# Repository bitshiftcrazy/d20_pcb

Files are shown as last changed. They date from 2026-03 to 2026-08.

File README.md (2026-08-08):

# d20 PCB

A handheld electronic D20 built as a DnD-themed PCB project.

The board uses an ATtiny84, charlieplexed LEDs, capacitive touch input,
custom animations, EEPROM-backed "attunement", and hidden easter eggs to
turn a PCB into a slightly magical-feeling tabletop artifact. For dice
rolls, dramatic failures, heroic last minutes, and other shenanigans ;)

<p align="center">
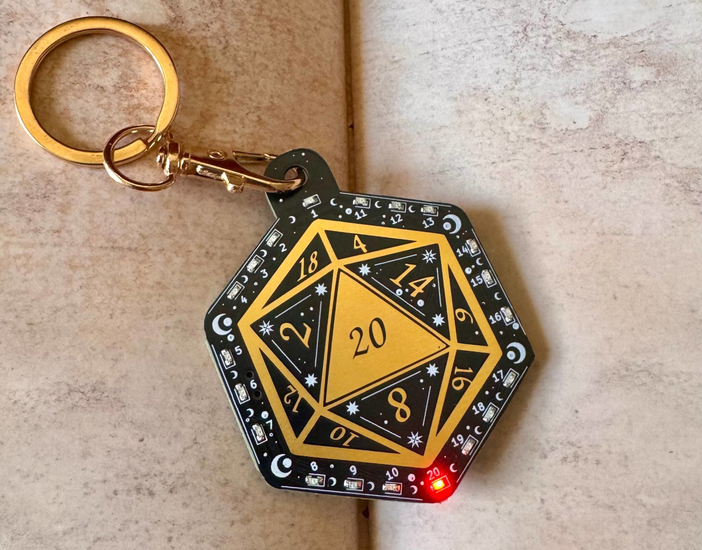
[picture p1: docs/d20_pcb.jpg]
  
</p>

## Features

- Electronic D20 with animated rolls
- Capacitive touch dice rolling
- Character-specific animation variants
- EEPROM-backed attunement system
- Hidden easter eggs and secret modes
- Fully open hardware and open source firmware
- Mildly questionable choices and amounts of whimsy

## Usage

### Power On

Turn on the board using the slide switch on the right side.

The board spends most of its existence asleep, patiently waiting for
an adventurer to wake it.

### Wake Up

Press the push button on the back once to wake the board.

The LEDs should come to life shortly afterwards.

### Rolling

Rolls can be triggered either by:

- pressing the push button
- briefly touching and releasing the `20` touch pad

The pushbutton has the power to interrupt rolls, should fate require it.

The touch sensor is intentionally configured conservatively to avoid
accidental triggers and random table wizardry (everyone who's seen an actual Pen and Paper table will know why).

Touch works best while holding the board in your hand and touching the
pad between thumb and index finger (there has been some discussion about
this...).

Touch sensitivity can be adjusted in `firmware/src/touch.c`.

See the firmware README for more information.

## Attunement

The board features a small "attunement" system inspired by magical items
in tabletop RPGs.

On first activation, the firmware stores a tiny hardware-specific value in
EEPROM based on touch pad readings. This subtly affects animation timing
and behavior, making each board feel ever so slightly different.

## Repository Structure

```text
hardware/   KiCad PCB design, manufacturing files and artwork
firmware/   ATtiny84 firmware and test infrastructure
docs/       Images and documentation assets
```

Detailed instructions are available in:

- [hardware/README.md](hardware/README.md)
- [firmware/README.md](firmware/README.md)

## Easter Eggs

The firmware contains several hidden interactions and modes and, yeah, an attitude.

Some are obvious.
Some are less obvious.

Some still haven't been found yet.

<p align="center">
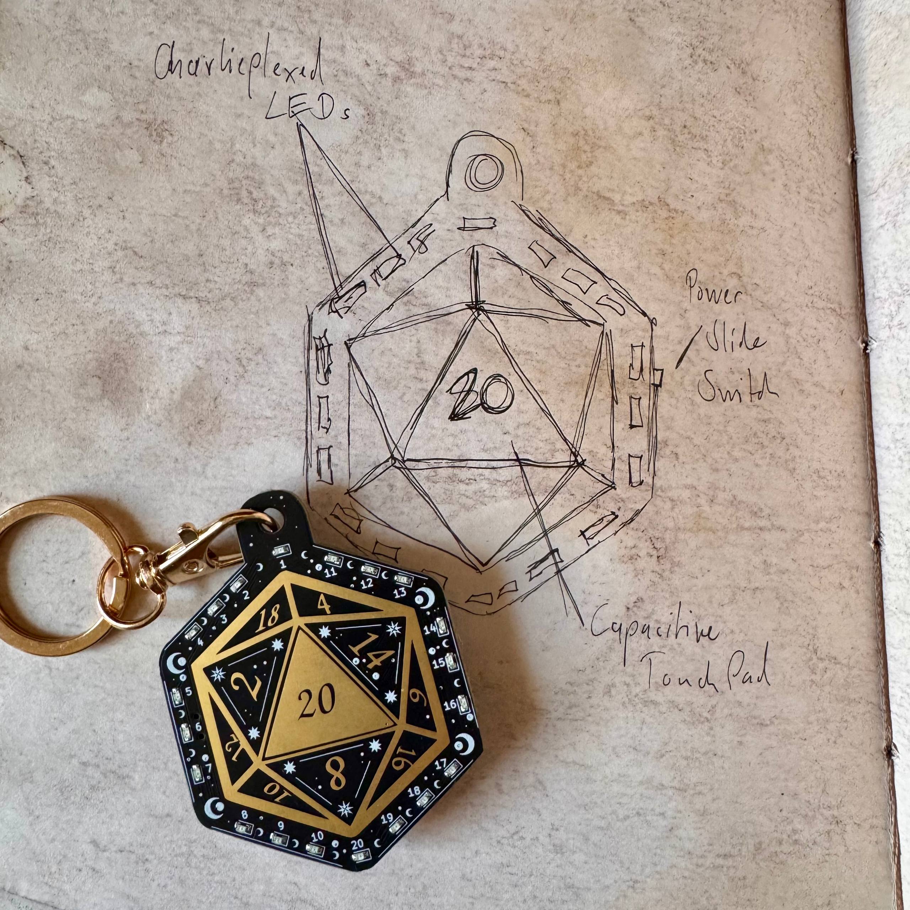
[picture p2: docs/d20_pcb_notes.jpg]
  
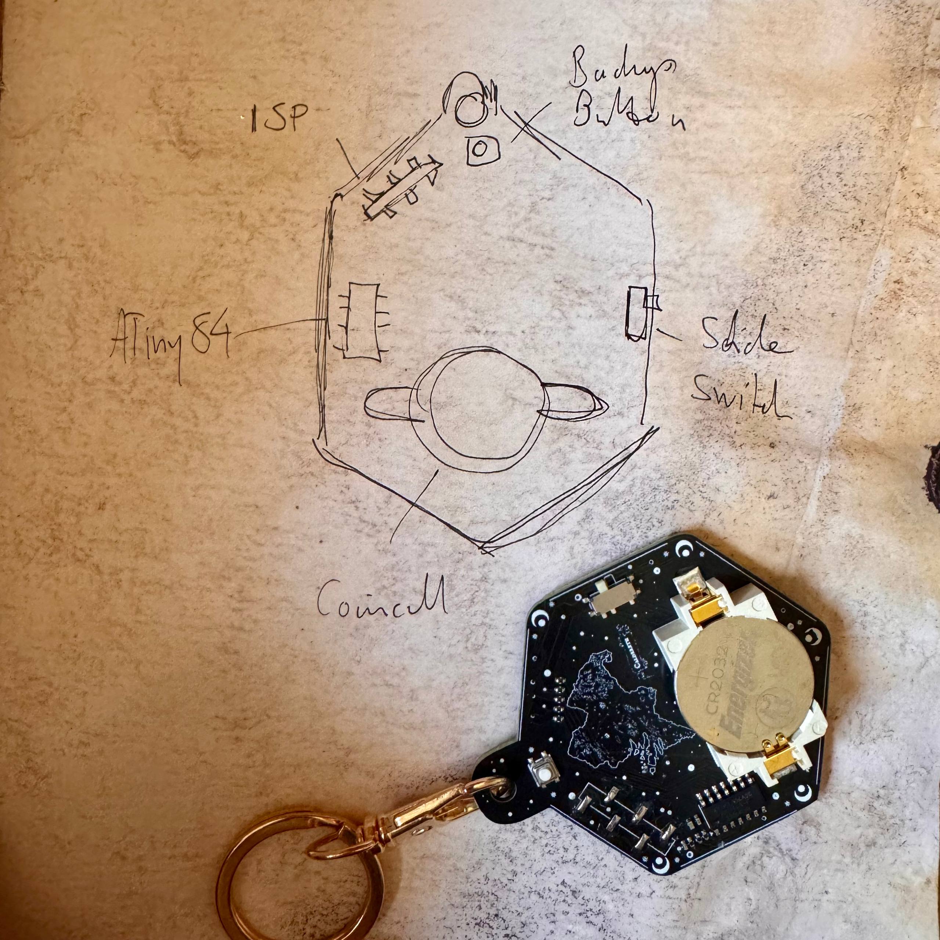
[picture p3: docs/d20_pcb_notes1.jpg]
  
</p>

## Project Background

This project originally started as a handmade DnD-themed gift for my
players, with far more LEDs, firmware, and suspicious EEPROM usage than originally planned.
And now it's an open hardware project.

There's customisation for both the players and the campaign hidden
throughout the project because of how it came to be.
The different character's animation can be interpreted as flavour and compiled in to your liking.

## Further Reading

- Project blog post: https://missmolerat.com/posts/d20_pcb/
- Hackaday: https://hackaday.com/2026/05/25/slightly-sentient-d20-might-subtly-shift-your-rolls/

## Licenses

- Hardware: CERN Open Hardware License
- Firmware: GPL-3.0-only

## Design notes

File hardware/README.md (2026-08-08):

# d20 PCB – Hardware

<p align="center">
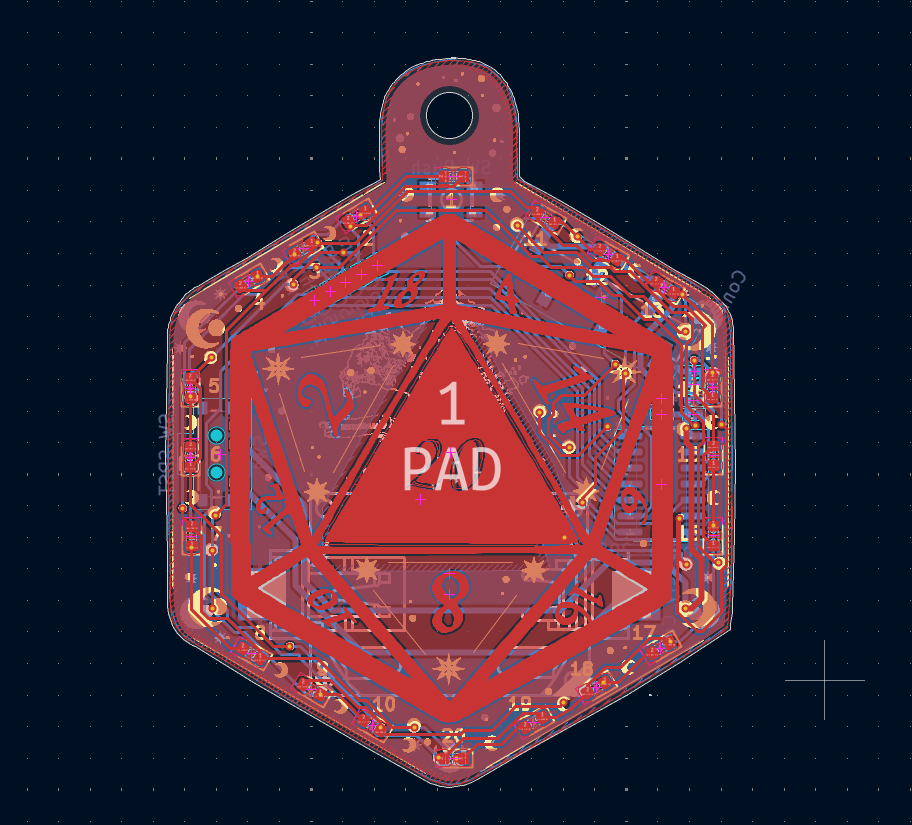
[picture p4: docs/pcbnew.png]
  
</p>

This directory contains the KiCad design files, artwork, and
manufacturing outputs for the d20 PCB.

The board is a small ATtiny-based electronic die with 20 LEDs arranged
around the edge of a d20-shaped PCB. A capacitive touch pad triggers a
roll animation and displays a random result.

## Hardware Overview

Main components:

- ATtiny84 microcontroller
- 20 LEDs arranged in a ring (charlieplexed)
- Capacitive touch pad for input
- Coin cell battery holder
- Push button (optional backup input)

## Directory Structure

```text
d20_pcb.kicad_pro
d20_pcb.kicad_sch
d20_pcb.kicad_pcb
```

KiCad project files.

```text
artwork/
```

SVG artwork used for silkscreen and copper layers.

```text
libraries/
```

Project-local KiCad symbol and footprint libraries.

```text
fabrication/
```

Generated manufacturing files:

- `gerbers/`
- `drill/`
- `bom/`
- `pickplace/`

```text
fabrication/jlcpcb/
```

Vendor-specific BOM and placement files for JLCPCB assembly.

### JLCPCB Component Substitutions

Component availability at JLCPCB/LCSC changes over time. During a 2026
JLCPCB assembly order, the following substitutions were proposed for the
v3 BOM:

| Designator | Original value / function | Substitute | Notes |
| --- | --- | --- | --- |
| C2 | 10 µF | C7472949 — HGC0402R5106M100NTEJ | 10 µF, 10 V, 0402 MLCC. Original C6119763 was out of stock. |
| R1–R5 | 150 Ω | C2909321 — FRC0402F1500TS | 150 Ω, 1%, 0402 |
| R7–R8 | 10 kΩ | C723366 — RT0402FRE0710KL | 10 kΩ, 1%, 0402 thin-film resistor, YAGEO |
| J1 | ISP header | C48641755 — HX PM2.54-1x6P | SMD female 1×6 header with staggered pins. The original BOM entry had no LCSC part number. |
| J2 and G* | — | DNP | No physical components fitted. |

The suggested C2 replacement is a ceramic MLCC rather than the capacitor
specified in the original BOM. Component substitutions should always be
reviewed before ordering, since stock and JLCPCB/LCSC part assignments
can change.

Thanks to [@dmaglio](https://github.com/dmaglio) for reporting these
substitutions in [issue #1](https://github.com/bitshiftcrazy/d20_pcb/issues/1).

## KiCad Project

The board is designed using KiCad.

Main files:

- `d20_pcb.kicad_pro` – project file
- `d20_pcb.kicad_sch` – schematic
- `d20_pcb.kicad_pcb` – PCB layout

The project uses local libraries located in:

```text
libraries/
```

## Artwork

Silkscreen and copper artwork is stored as SVG files in:

```text
artwork/
```

These files were used to create decorative PCB elements such as:

- board outline
- line art
- map on the back
- decorative stars and moons

## Manufacturing

<p align="center">
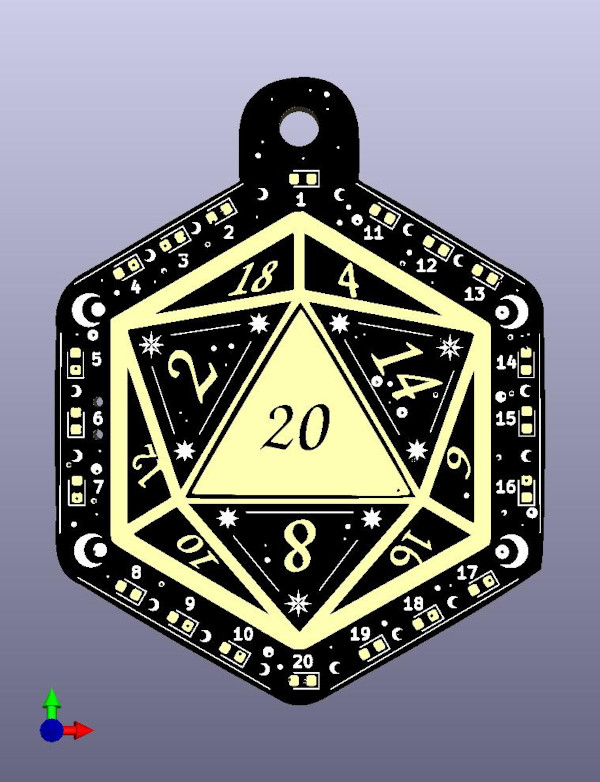
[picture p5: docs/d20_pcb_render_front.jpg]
  
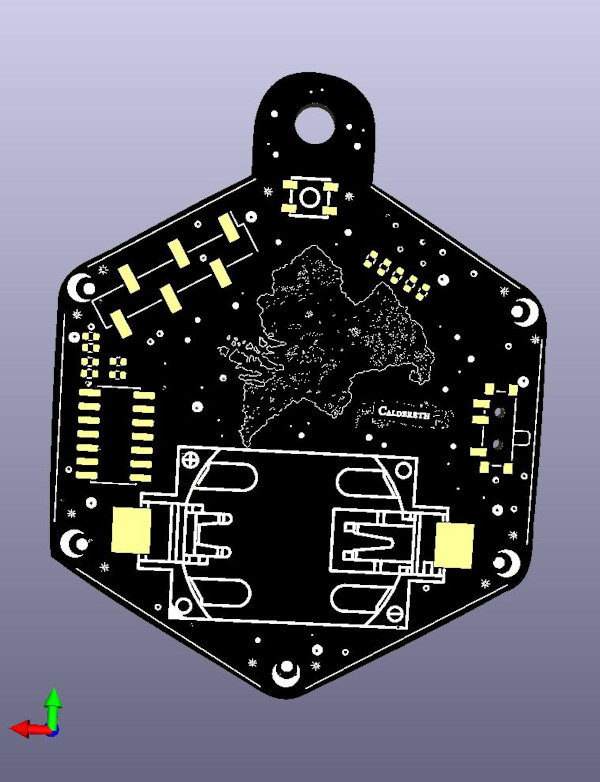
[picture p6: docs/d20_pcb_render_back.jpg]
  
</p>

All required manufacturing outputs are located in:

```text
fabrication/
```

To manufacture the board:

1. Upload files from `fabrication/gerbers/` to a PCB manufacturer.
2. Use files from `fabrication/drill/` for drilling information.
3. Use the BOM and pick-and-place files for assembly.

Note: the more detailed assembly BOM with parts and values is located in:

```text
fabrication/jlcpcb/
```

Alternatively:

The files in `fabrication/releases/` contain the currently tested and
successfully manufactured board revision.

If you modify the KiCad source files, you should regenerate and review
all fabrication outputs (Gerbers, drill files, BOM, and pick-and-place
files) before ordering boards.

Even small PCB edits can invalidate previously generated fabrication
files.

If you are new to PCB manufacturing, it is recommended to use the tested
release files directly instead of generating new Gerbers yourself.

## Regenerating Fabrication Files

Manufacturing files can be regenerated from KiCad:

```text
PCB Editor → Fabrication Outputs
```

## Assembly

### Supplies

* soldering iron (alternatively: heat plate or hot air)
* solder (alternatively: solder paste)
* flux
* fume extractor or a well-ventilated space

### Parts

Many of the parts are influenced by what I had at home at the time.

Quite a few can be swapped for whatever matches the footprint. I found that old TV remotes are wonderful donors for slide switches and push buttons, for example. At least that's where I got these components from.

* 20 x SMD LEDs (0603)
* 1 x 0.1 µF capacitor (0402)
* 1 x 10 µF capacitor (0402)
* 1 x 10 nF capacitor (0402)
* 5 x 150 Ω resistors (0402)
* 2 x 10 kΩ resistors (0402)
* 1 x 1 MΩ resistor (0402)
* 1 x Keystone 1060TR battery holder
* 1 x CR2032 coin cell battery
* 1 x ATtiny84-20P Microchip ATTINY84A-SSF
* 1 x SPDT slide switch (see footprint; many ~8 mm SMD slide switches will fit, AliExpress has quite a few)
* 1 x push button (same here; 3.4 x 3.4 mm SMD push buttons often work)

I'd really love to point towards specific components for the slide switch or push button. But apart from sourcing the part via JLCPCB assembly or scavenging it, I have none.

Really, have faith: as long as you manage to connect the footprint pads with the part pins somehow, a lot of switches will work here (source: trust me bro).

### Soldering

<p align="center">
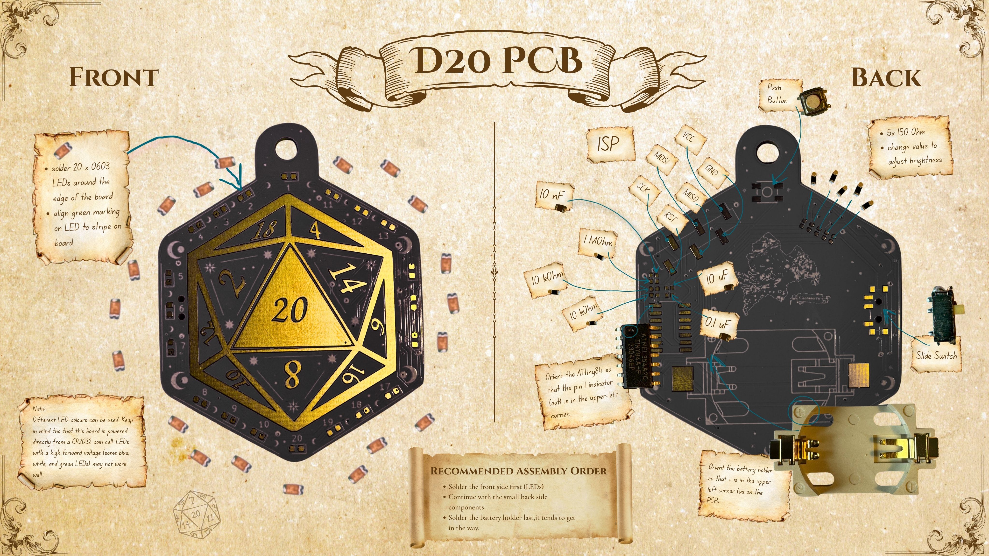
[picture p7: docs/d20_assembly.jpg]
  
</p>

## Colour Suggestions

The board was intentionally designed with colourful solder masks and
ENIG finishes in mind.

~~I'd really love to see a pink board!~~

Mission accomplished :D

<p align="center">
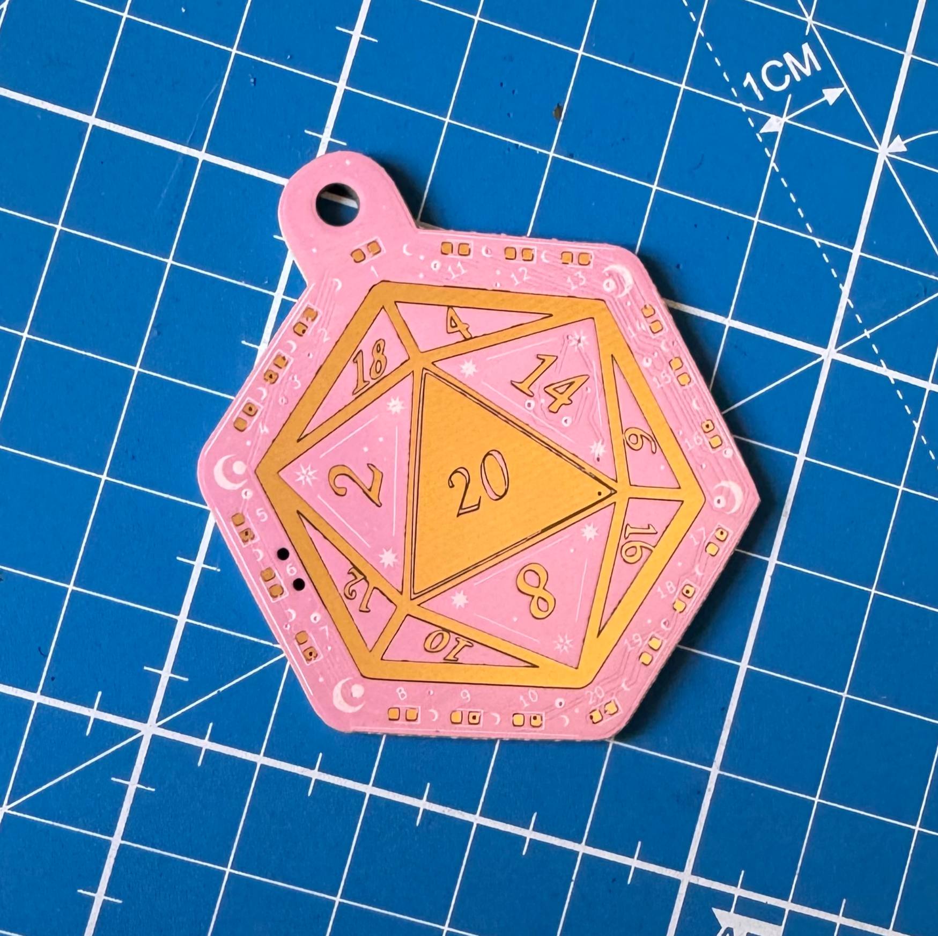
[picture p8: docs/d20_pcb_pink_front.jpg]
  
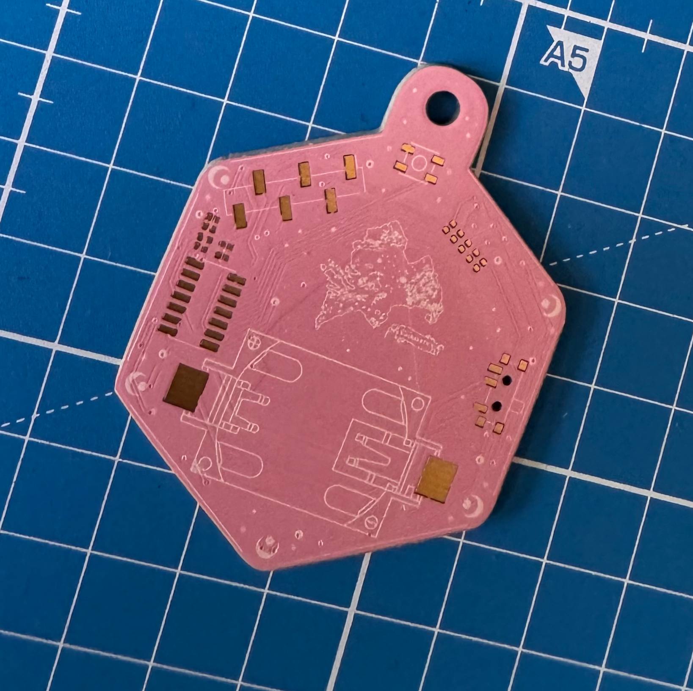
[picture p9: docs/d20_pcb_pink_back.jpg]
  
</p>

<p align="center">
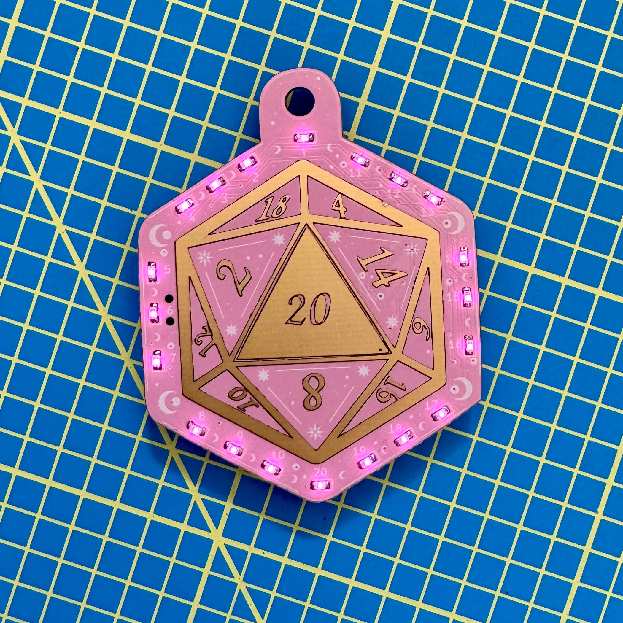
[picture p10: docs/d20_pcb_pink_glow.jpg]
  
</p>

For comparison, here are the original render concepts:

<p align="center">
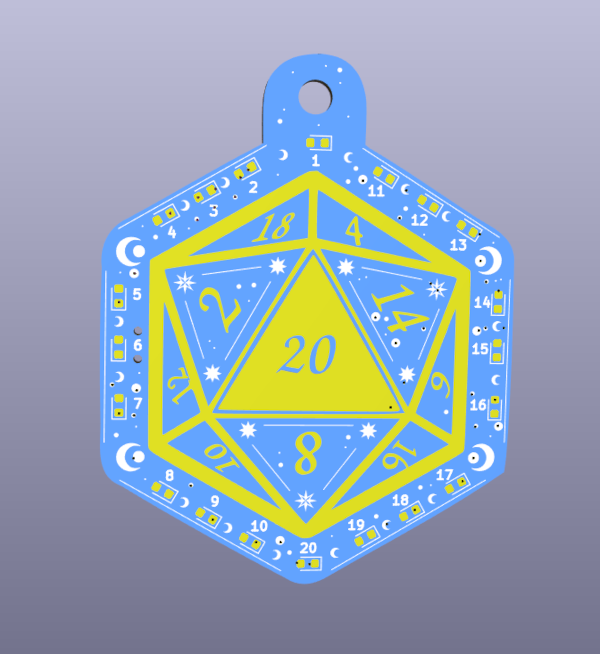
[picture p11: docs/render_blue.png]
  
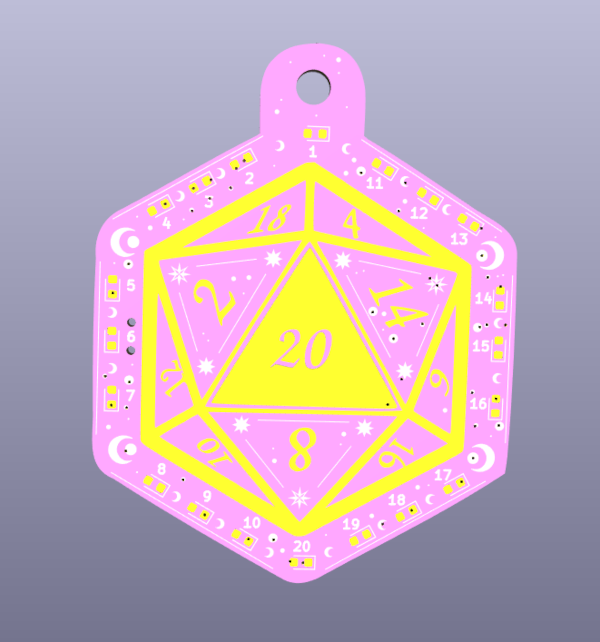
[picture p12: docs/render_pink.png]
  
</p>

## License

This hardware design is licensed under the CERN Open Hardware Licence
Version 2 – Strongly Reciprocal (CERN-OHL-S v2).

You may manufacture, modify and sell products based on this design,
provided that any modifications to the design files are released under
the same license.

The full license text is available in the LICENSE file.

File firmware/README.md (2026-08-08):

# d20 PCB Firmware

Firmware for the d20 PCB project.

This firmware runs on an **ATtiny84** and controls the charlieplexed LEDs,
button input, capacitive touch input, EEPROM-backed attunement state, dice
roll logic, animations, and some easter eggs.

The following instructions assume firmware is built and flashed from Linux.

## Hardware Requirements

To program the board, you need:

- d20 PCB with ATtiny84 (see [hardware/](../hardware))
- ISP programmer, for example USBasp
- ISP connection to the board
- Linux machine with AVR toolchain installed

The Makefile currently assumes a USBasp programmer.

## Software Requirements

Install the AVR toolchain.

### Arch Linux

```sh
sudo pacman -S avr-gcc avr-libc avrdude make
```

### Debian / Ubuntu

```sh
sudo apt install gcc-avr avr-libc avrdude make
```

## Building

From the repository root:

```sh
cd firmware
make
```

This builds the default firmware and prints AVR memory usage.

Build output is written to:

```text
build/
```

The generated firmware image is:

```text
build/d20_firmware_4.hex
```

The default character ID is currently `4`.

## Character Selection

Since the project originates from a gift for my DnD players, the firmware
supports different character-specific builds through `CHARACTER_ID`.

```sh
make CHARACTER_ID=4
```

Known character IDs:

```text
1 = ASHTAN
2 = BARTHOLOMEW
3 = FAWN
4 = SALEM
5 = VII
```

Example:

```sh
make flash CHARACTER_ID=2
```

## Fuse Bits

Before flashing the firmware for the first time, program the ATtiny84 fuse
bits:

```sh
make fuses
```

This configures the microcontroller to use the 8 MHz clock settings expected by the firmware.

Fuse bits only need to be programmed once per microcontroller.

## Flashing

To build and flash the firmware with a USBasp programmer:

```sh
make flash
```

This uses:

```text
avrdude -c usbasp -p t84 -B 10
```

To flash a different character firmware:

```sh
make flash CHARACTER_ID=5
```

## Diagnostic Test Firmware

The firmware includes small functional and diagnostic test builds.

These are not full unit tests. They are intended to flash special test
firmware onto the board to verify individual hardware or firmware features.

Build a test firmware without flashing:

```sh
make test TEST_CASE=attunement
```

Build and flash a selected test firmware:

```sh
make flash-test TEST_CASE=adc_band_finder
```

Available test cases:

```text
led_walk
button_toggle
button_hold
adc_range
touch_detect
touch_long
adc_band_finder
attunement
sequence
```

Shortcut targets are also available:

```sh
make test-led-walk
make test-button-toggle
make test-button-hold
make test-adc-range
make test-touch-detect
make test-touch-long
make test-adc-band-finder
make test-attunement
make test-sequence
```

## EEPROM Helpers

Read the ATtiny84 EEPROM into `build/eeprom.hex`:

```sh
make eeprom-read
```

Read and print EEPROM contents:

```sh
make eeprom-view
```

This is useful for checking attunement state and debugging persistent firmware
state.

## Cleaning

Remove build output:

```sh
make clean
```

## Makefile Overview

Useful targets:

```text
make all          Build firmware hex and show size
make flash        Build and flash normal firmware
make test         Build diagnostic test firmware
make flash-test   Build and flash diagnostic test firmware
make size         Show AVR memory usage
make eeprom-read  Read EEPROM into build/eeprom.hex
make eeprom-view  Read and print EEPROM contents
make clean        Remove build output
make help         Show Makefile help
```

Useful options:

```text
CHARACTER_ID=N    Select character firmware variant
TEST=1            Build test firmware instead of normal firmware
TEST_CASE=name    Select diagnostic test case
```

## Firmware Configuration and Tuning

The main configuration is done in `src/config.h`.

Touch sensing can be adjusted in `src/touch.c`.

You can use the diagnostic test firmware targets:

- `test-adc-range`
- `test-adc-band-finder`

to inspect and tune touch detection thresholds for your hardware.

## Hardware Compatibility

This firmware is intended for the d20 PCB hardware revisions developed in
this repository.

If using modified hardware revisions, verify:

- LED pin mappings
- touchpad routing
- ISP wiring
- EEPROM layout assumptions

before flashing the firmware.

## License

This firmware is licensed under GPL-3.0-only.

See `LICENSE` for details.

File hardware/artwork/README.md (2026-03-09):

SVG source artwork used for PCB graphics.

board/
  Artwork used directly in the PCB design.

symbols/
  Small reusable decorative elements that can be imported
  into KiCad silkscreen layers.

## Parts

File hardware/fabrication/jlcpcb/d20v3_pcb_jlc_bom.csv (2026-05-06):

Comment | Designator | Footprint | LCSC
Battery_Cell | BT1 | d20_pcb:d20_battery | C238069
0.1uF | C1(Ceramic)1 | Capacitor_SMD:C_0402_1005Metric | C141382
10uF | C2(Electrolytic)1 | Capacitor_SMD:C_0402_1005Metric | C6119763
10nF | C3 | Capacitor_SMD:C_0402_1005Metric | C15195
LED | D1,D2,D3,D4,D5,D6,D7,D8,D9,D10,D11,D12,D13,D14,D15,D16,D17,D18,D19,D20 | LED_SMD:LED_0603_1608Metric | C19171390
Conn_01x06_Socket | J1 | Connector_PinHeader_2.54mm:PinHeader_1x06_P2.54mm_Vertical_SMD_Pin1Left
Conn_01x01_Pin | J2 | d20_pcb:d20_touchpad
150 Ohm | R1,R2,R3,R4,R5 | Resistor_SMD:R_0402_1005Metric | C25082
1MOhm | R6 | Resistor_SMD:R_0402_1005Metric | C26083
10kOhm | R7,R8 | Resistor_SMD:R_0402_1005Metric | C102749
SW_SPST | SW1 | Button_Switch_SMD:SW_SPDT_PCM12 | C431540
SW_Push | SW2 | d20_pcb:d20_pushbutton | C596271
ATtiny84-20P | U1 | Package_SO:SOIC-14_3.9x8.7mm_P1.27mm | C1340034

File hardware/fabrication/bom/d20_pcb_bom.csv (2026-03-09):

Id | Designator | Footprint | Quantity | Designation | Supplier and ref
1 | D7,D10,D6,D19,D4,D20,D18,D1,D12,D16,D13,D5,D15,D9,D3,D17,D14,D11,D8,D2 | LED_0603_1608Metric | 20 | LED
2 | J2 | d20_touchpad | 1 | Conn_01x01_Pin
3 | G*** | d20_line_art | 1 | d20_line_art
4 | R8,R7 | R_0402_1005Metric | 2 | 10kOhm
5 | R6 | R_0402_1005Metric | 1 | 1MOhm
6 | J1 | PinHeader_1x06_P2.54mm_Vertical_SMD_Pin1Left | 1 | Conn_01x06_Socket
7 | U1 | SOIC-14_3.9x8.7mm_P1.27mm | 1 | ATtiny84-20P
8 | R2,R3,R1,R4,R5 | R_0402_1005Metric | 5 | 150 Ohm
9 | C2(Electrolytic)1 | C_0402_1005Metric | 1 | 10uF
10 | SW2 | d20_pushbutton | 1 | SW_Push
11 | C3 | C_0402_1005Metric | 1 | 10nF
12 | BT1 | d20_battery | 1 | Battery_Cell
13 | SW1 | SW_SPDT_PCM12 | 1 | SW_SPST
14 | C1(Ceramic)1 | C_0402_1005Metric | 1 | 0.1uF

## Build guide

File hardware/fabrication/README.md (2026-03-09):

# Fabrication Files

This directory contains manufacturing outputs generated from the KiCad
project.

## Generic files
- `gerbers/` Gerber files for PCB fabrication
- `drill/` Drill files
- `pickplace/` Generic component placement files
- `bom/` Generic bill of materials

## JLCPCB-specific files
- `jlcpcb/` BOM and placement files adjusted for JLCPCB assembly
   (note: this BOM contains values and parts)

These files can be regenerated from the KiCad sources in `hardware/`.

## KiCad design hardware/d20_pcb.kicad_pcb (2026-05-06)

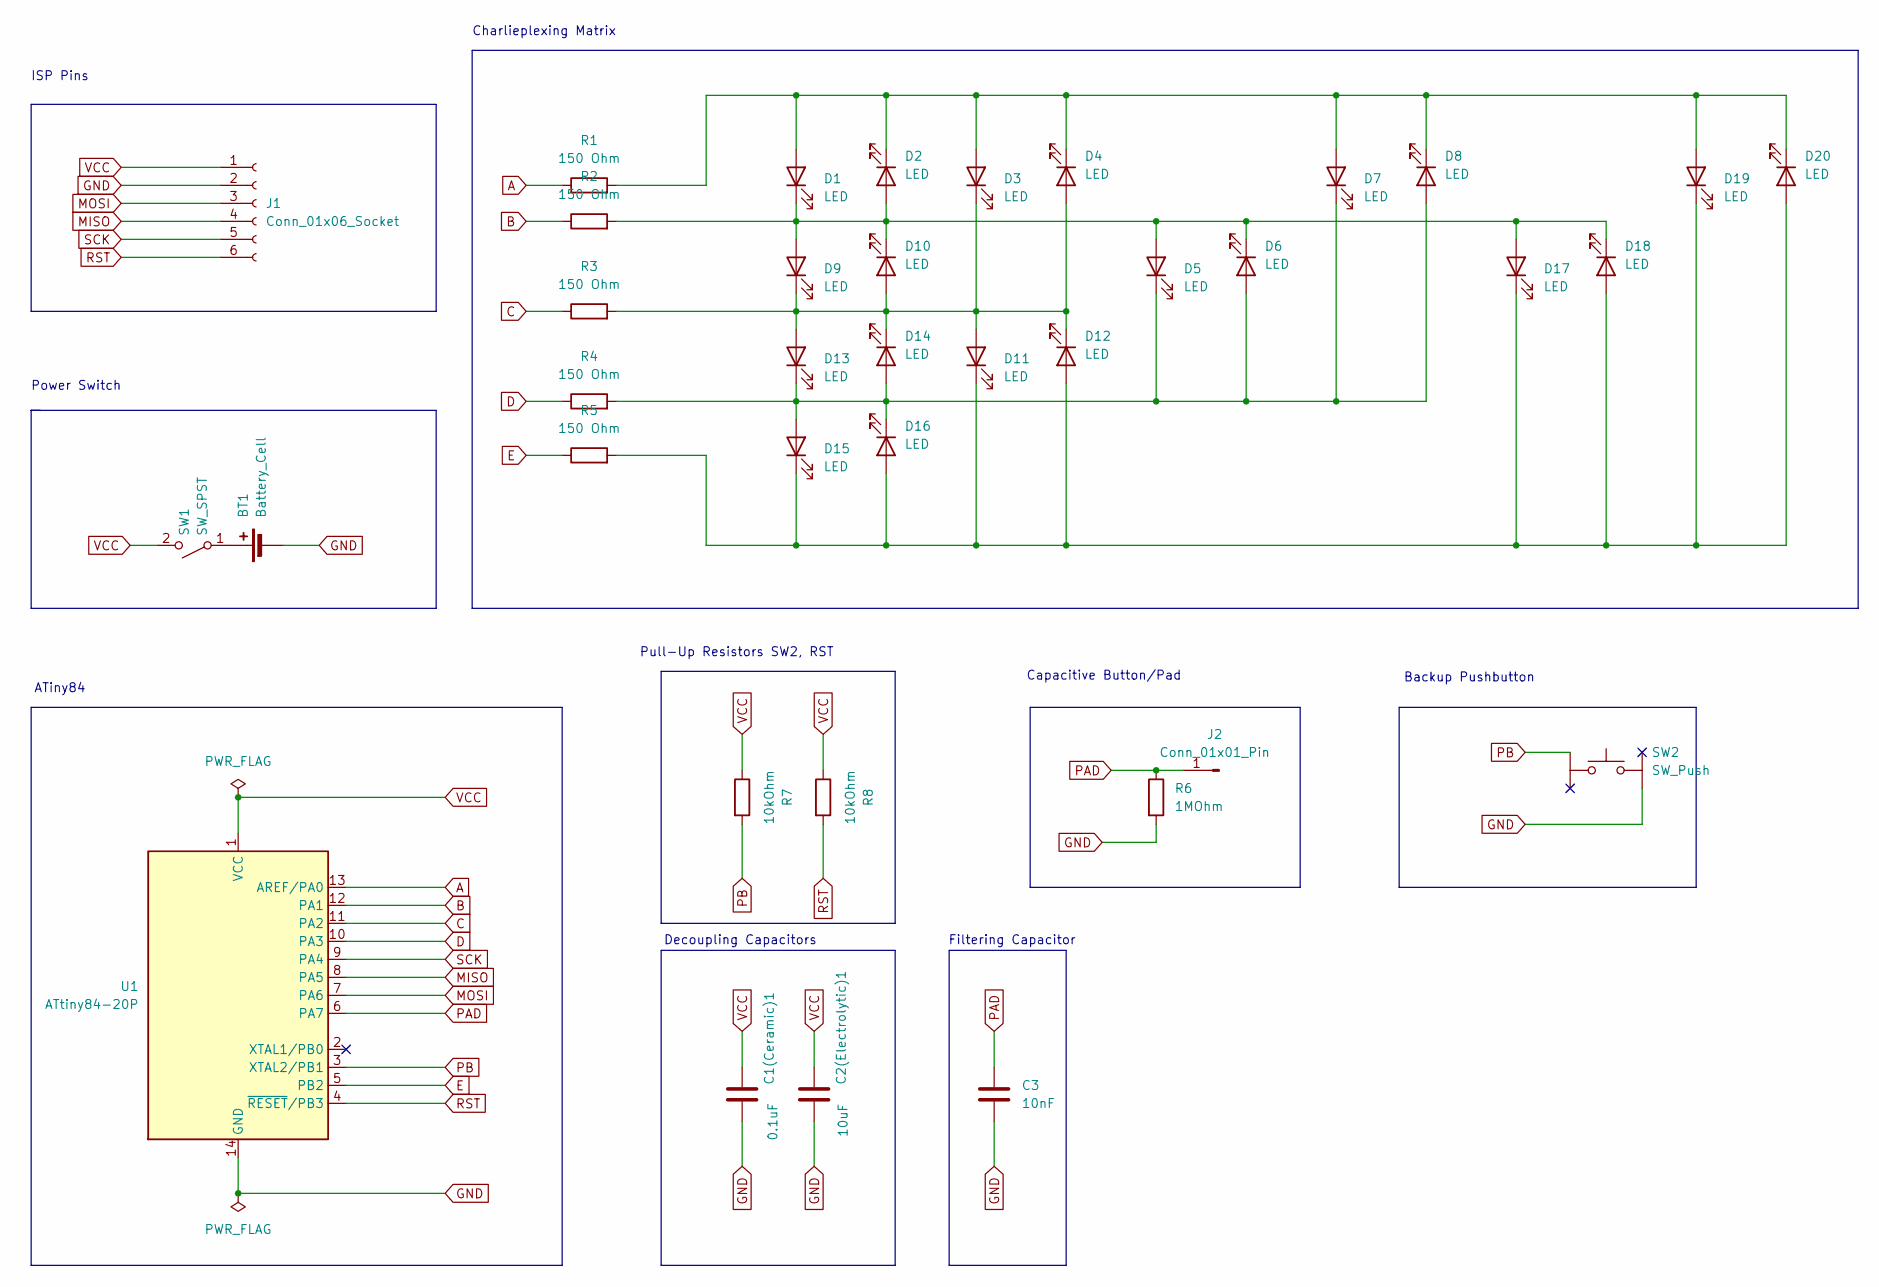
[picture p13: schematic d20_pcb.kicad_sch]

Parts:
BT1: Battery_Cell; d20_battery; LCSC C238069
C1(Ceramic)1: 0.1uF; C_0402_1005Metric; LCSC C141382
C2(Electrolytic)1: 10uF; C_0402_1005Metric; LCSC C6119763
C3: 10nF; C_0402_1005Metric
D1, D2, D3, D4, D5, D6, D7, D8, D9, D10, D11, D12, D13, D14, D15, D16, D17, D18, D19, D20: LED; LED_0603_1608Metric; LCSC C19171390
J1: Conn_01x06_Socket; PinHeader_1x06_P2.54mm_Vertical_SMD_Pin1Left
J2: Conn_01x01_Pin; d20_touchpad
R1, R2, R3, R4, R5: 150 Ohm; R_0402_1005Metric; LCSC C25082
R6: 1MOhm; R_0402_1005Metric; LCSC C26083
R7, R8: 10kOhm; R_0402_1005Metric; LCSC C102749
SW1: SW_SPST; SW_SPDT_PCM12; LCSC C431540
SW2: SW_Push; d20_pushbutton; LCSC C596271
U1: ATtiny84-20P; SOIC-14_3.9x8.7mm_P1.27mm; LCSC C1340034

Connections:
A: R1.1, U1.13 (AREF/PA0)
B: R2.1, U1.12 (PA1)
C: R3.1, U1.11 (PA2)
D: R4.1, U1.10 (PA3)
E: R5.1, U1.5 (PB2)
GND: BT1.2 (-), C1(Ceramic)1.2, C2(Electrolytic)1.2, C3.2, J1.2, R6.2, SW2.4, U1.14 (GND)
MISO: J1.4, U1.8 (PA5)
MOSI: J1.3, U1.7 (PA6)
unnamed: BT1.1 (+), SW1.1 (A)
unnamed: D1.2 (A), D2.1 (K), D3.2 (A), D4.1 (K), D7.2 (A), D8.1 (K), D19.2 (A), D20.1 (K), R1.2
unnamed: D1.1 (K), D2.2 (A), D5.2 (A), D6.1 (K), D9.2 (A), D10.1 (K), D17.2 (A), D18.1 (K), R2.2
unnamed: D3.1 (K), D4.2 (A), D9.1 (K), D10.2 (A), D11.2 (A), D12.1 (K), D13.2 (A), D14.1 (K), R3.2
unnamed: D11.1 (K), D12.2 (A), D15.1 (K), D16.2 (A), D17.1 (K), D18.2 (A), D19.1 (K), D20.2 (A), R5.2
unnamed: D5.1 (K), D6.2 (A), D7.1 (K), D8.2 (A), D13.1 (K), D14.2 (A), D15.2 (A), D16.1 (K), R4.2
PAD: C3.1, J2.1 (Pin_1_1), R6.1, U1.6 (PA7)
PB: R7.2, SW2.1, U1.3 (XTAL2/PB1)
RST: J1.6, R8.2, U1.4 (~RESET/PB3)
SCK: J1.5, U1.9 (PA4)
VCC: C1(Ceramic)1.1, C2(Electrolytic)1.1, J1.1, R7.1, R8.1, SW1.2 (B), U1.1 (VCC)

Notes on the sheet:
Decoupling Capacitors
Backup Pushbutton
Capacitive Button/Pad
ATiny84
Pull-Up Resistors SW2, RST
ISP Pins
Power Switch
Charlieplexing Matrix
Filtering Capacitor

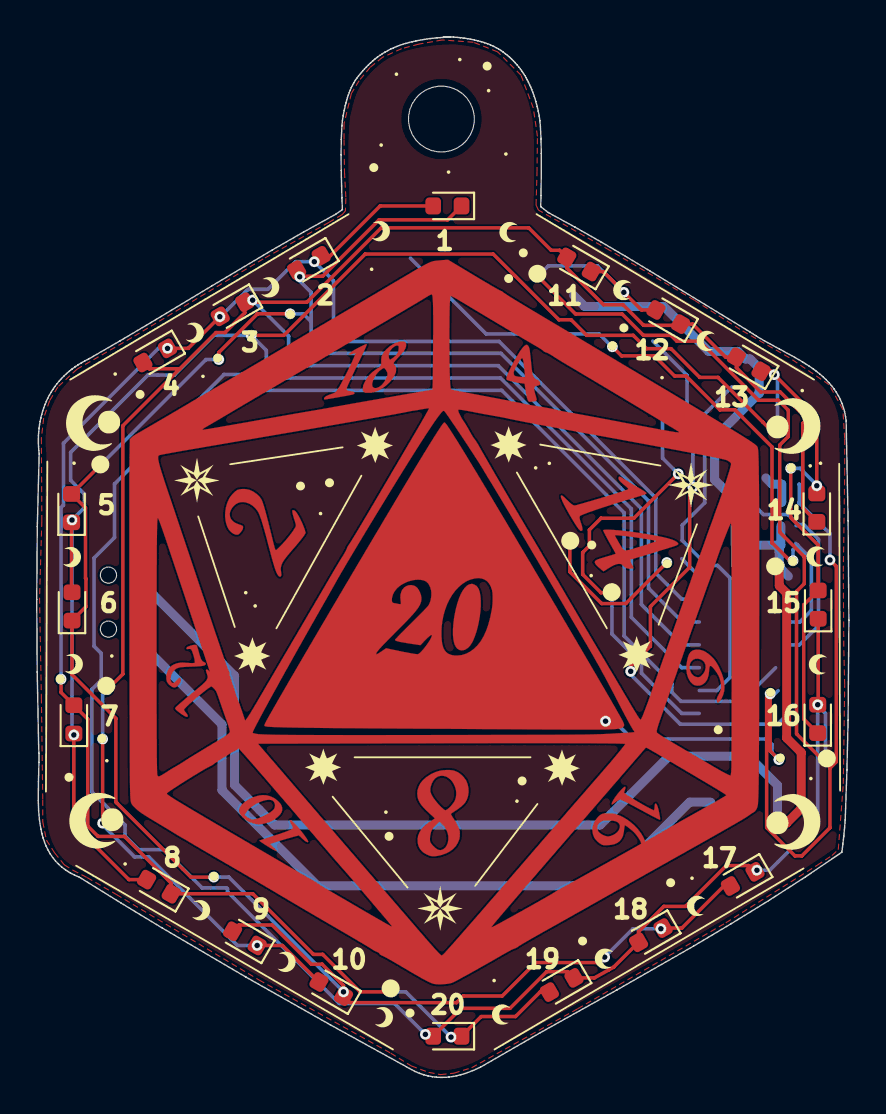
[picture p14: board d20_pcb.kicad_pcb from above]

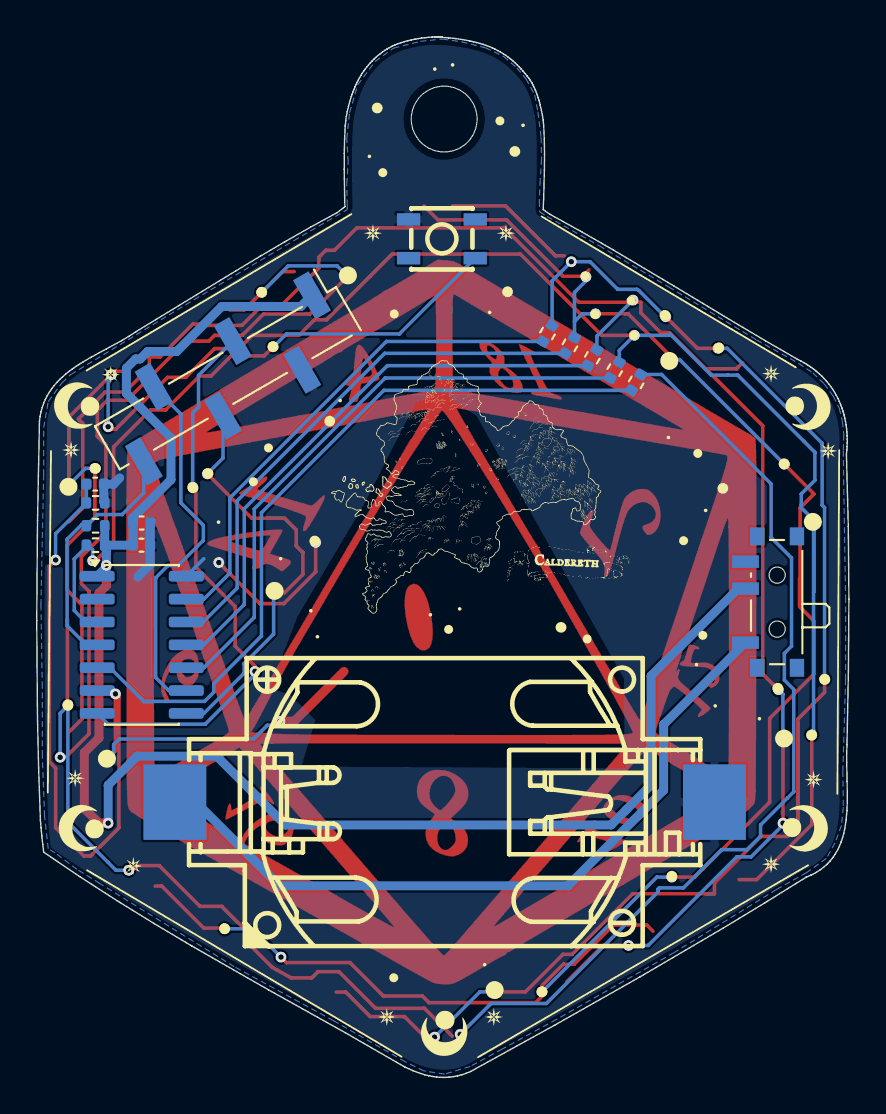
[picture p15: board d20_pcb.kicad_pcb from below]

Board: 2 copper layers, 45.1 x 57.8 mm, 37 parts (16 on the bottom side), 19 nets.

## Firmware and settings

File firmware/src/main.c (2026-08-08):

/*
 * SPDX-License-Identifier: GPL-3.0-only
 *
 * Copyright (C) 2025 miss.molerat <bitshiftcrazy@posteo.de>
 */

#include <stdbool.h>
#include <stdint.h>
#include <avr/interrupt.h>

#include "adc.h"
#include "animations.h"
#include "attunement.h"
#include "button.h"
#include "charlieplex.h"
#include "pins.h"
#include "roll.h"
#include "timer.h"
#include "touch.h"
#include "sequence.h"

/*
 * Application entry point and top-level state machine.
 *
 * This is the part where the artifact wakes up.
 *
 * The firmware behaves like a small ritual with four phases:
 *
 *   WAIT_FOR_START
 *     - the dice is dormant, it listens, but does not respond
 *     - only an adventurer's decisive button press will wake it
 *
 *   IDLE
 *     - the dice is awake and bound to its bearer
 *     - touch or button may invoke a roll
 *     - a long press re-forges the attunement bond
 *     - if certain conditions are met, it may begin to... misbehave
 *
 *   COOLDOWN
 *     - the dice settles after a roll
 *     - touch is ignored to prevent accidental retriggering
 *     - button input may still provoke it into acting again
 *
 *   SEQUENCE
 *
 * Input model
 * -----------
 * - Button:
 *     - short press → invoke roll / contribute to hidden sequences
 *     - long press  → break and re-establish attunement
 *
 * - Touch:
 *     - event-based trigger
 *     - ignored during cooldown
 *
 * Notes
 * -----
 * - hardware initialization happens here
 * - most animations require concentration from the dice (i.e. blocking rituals)
 * - this file coordinates the threads of the weave, but does not decide fate
 */

/* ------------------------------------------------------------------------- */
/* App state                                                                 */
/* ------------------------------------------------------------------------- */
/*
 * Brief settling period after invoking fate.
 * Button presses bypass this and can reroll immediately.
 */
#define TOUCH_REARM_MS 350UL

typedef enum {
    APP_STATE_WAIT_FOR_START = 0,
    APP_STATE_IDLE,
    APP_STATE_COOLDOWN,
    APP_STATE_SEQUENCE
} app_state_t;

static app_state_t app_state = APP_STATE_WAIT_FOR_START;
static uint32_t cooldown_start_ms = 0UL;

/* ------------------------------------------------------------------------- */
/* Internal helpers                                                          */
/* ------------------------------------------------------------------------- */

/* Cheap (non-cryptographic ;)) entropy mixing from touch ADC, time, and attunement state */
static uint16_t app_collect_entropy(uint32_t now_ms)
{
    uint16_t entropy = 0U;

    entropy ^= adc_read(TOUCH_ADC_CHANNEL);
    entropy ^= (uint16_t)now_ms;
    entropy ^= (uint16_t)(now_ms >> 16);
    entropy ^= (uint16_t)((uint16_t)attunement_get_value() << 8);
    entropy ^= 0xA55AU;

    return entropy;
}

static void app_enter_cooldown(uint32_t now_ms)
{
    cooldown_start_ms = now_ms;
    app_state = APP_STATE_COOLDOWN;
    charlieplex_all_off();
}

static void app_run_attunement_sequence(void)
{
    /*
     * Re-attunement is a dedicated blocking ritual and requires concentration.
     * During this time, we intentionally ignore button/touch input.
     */
    roll_seed_entropy(app_collect_entropy(millis()));

    (void)attunement_measure_and_store();

    /*
     * Animations derive timing/variation from attunement, so re-init them
     * after a newly measured value is available.
     */
    animations_init();

    /* Feed the newly forged attunement back into the weave. */
    roll_seed_entropy((uint16_t)attunement_get_value() << 8);

    /*
     * Reset touch detector state after the ritual so stale lock state or
     * half-built sampling history does not leak into normal operation.
     */
    touch_init();

    animations_play_attunement();

    button_init();
    touch_init();

    charlieplex_all_off();
    app_enter_cooldown(millis());
}

static void app_start_roll(uint32_t now_ms)
{
    /* reroll until committed, unless long-press triggers into re-attunement */
    while (1) {
        roll_result_t result;
        anim_roll_status_t anim_status;

        roll_seed_entropy(app_collect_entropy(now_ms));
        result = roll_perform();

        if (roll_upset_should_glitch_animation()) {
            animations_flash_all(1U, 25U, 40U);
        }

        anim_status = animations_play_roll(result.value);

        if (anim_status == ANIM_ROLL_COMPLETED) {
            if (result.is_nat20) {
                animations_play_nat20();
            }

            charlieplex_all_off();
            app_enter_cooldown(millis());
            return;
        }

        if (anim_status == ANIM_ROLL_ABORT_LONG) {
            app_run_attunement_sequence();
            return;
        }

        /*
         * Short press interrupted the roll animation.
         * Every short button press contributes to a hidden sequence.
         * Eleven in a row may... change things.
         * Count it toward the "hidden" (sooo hidden...) 11-press sequence,
         * then immediately reroll.
         */
        now_ms = millis();
        roll_note_button_press(now_ms);
    }
}

static bool app_handle_long_press(void)
{
    if (!button_long()) {
        return false;
    }

    app_run_attunement_sequence();
    return true;
}

/* ------------------------------------------------------------------------- */
/* Main loop                                                                 */
/* ------------------------------------------------------------------------- */

int main(void)
{
    uint32_t now_ms;
    uint16_t seed;

    charlieplex_init();
    adc_init();
    button_init();
    touch_init();
    timer_init();
    /* Enable global interrupts after timer setup */
    sei();
    attunement_init();
    sequence_init();

    seed = app_collect_entropy(millis());
    roll_init(seed);

    if (attunement_has_value()) {
        animations_init();
        roll_seed_entropy((uint16_t)attunement_get_value() << 8);
    }

    app_state = APP_STATE_WAIT_FOR_START;
    charlieplex_all_off();

    while (1) {
        now_ms = millis();

        button_update(now_ms);
        touch_update();

        switch (app_state) {
        case APP_STATE_WAIT_FOR_START:
            /*
             * The artifact is powered, but not yet awake.
             * Ignore touch and wait for a deliberate button press.
             * The start press does NOT count as a roll trigger or godmode tap.
             */
            (void)touch_triggered();
			(void)touch_long();
            charlieplex_all_off();

            if (button_pressed()) {
                if (attunement_has_value()) {
                    app_state = APP_STATE_IDLE;
                    charlieplex_all_off();
                } else {
                    app_run_attunement_sequence();
                }
            }
            break;

        case APP_STATE_IDLE:
            if (app_handle_long_press()) {
                break;
            }

            if (button_pressed()) {
                /*
                 * Every short button press counts toward the "hidden" (yeah...)
                 * 11-tap "super secret" god mode sequence (hi, I'm an easter egg).
                 */
                roll_note_button_press(now_ms);

                if (roll_upset_should_ignore_input()) {
                    animations_flash_all(1U, 15U, 30U);
                    break;
                }

                app_start_roll(now_ms);
                break;
            }

            if (touch_long()) {
                sequence_enter();
                app_state = APP_STATE_SEQUENCE;
                break;
            }

            if (touch_triggered()) {
                if (roll_upset_should_ignore_input()) {
                    animations_flash_all(1U, 15U, 30U);
                    break;
                }

                app_start_roll(now_ms);
                break;
            }

            if (roll_godmode_active()) {
                animations_godmode_pulse_step(now_ms);
            } else {
                charlieplex_all_off();
            }
            break;

        case APP_STATE_COOLDOWN:
            if (app_handle_long_press()) {
                break;
            }

            /*
             * The button has the power to force a response, even when touch is ignored.
             * This gives immediate reroll from button during the post-roll dead time.
             */
            if (button_pressed()) {
                roll_note_button_press(now_ms);

                if (roll_upset_should_ignore_input()) {
                    animations_flash_all(1U, 15U, 30U);
                    break;
                }

                app_start_roll(now_ms);
                break;
            }

            /*
             * Touch is intentionally ignored during cooldown, but we still
             * consume any one-shot trigger so it does not fire stale later.
             */
            (void)touch_triggered();
            (void)touch_long();

            if ((uint32_t)(now_ms - cooldown_start_ms) >= TOUCH_REARM_MS) {
                app_state = APP_STATE_IDLE;
                charlieplex_all_off();
            } else if (roll_godmode_active()) {
                animations_godmode_pulse_step(now_ms);
            } else {
                charlieplex_all_off();
            }
            break;

        case APP_STATE_SEQUENCE:
            sequence_update(now_ms);

            if (!sequence_active()) {
                button_init();
                touch_init();
                app_enter_cooldown(millis());
            }
            break;

        default:
            app_state = APP_STATE_WAIT_FOR_START;
            charlieplex_all_off();
            break;
        }
    }
}

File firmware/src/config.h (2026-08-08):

/*
 * SPDX-License-Identifier: GPL-3.0-only
 *
 * Copyright (C) 2025 miss.molerat <bitshiftcrazy@posteo.de>
 */

#ifndef CONFIG_H
#define CONFIG_H

/* -------------------------------------------------------------------------- */
/* Core clock                                                                 */
/* -------------------------------------------------------------------------- */

#ifndef F_CPU
#define F_CPU                    8000000UL
#endif

/* -------------------------------------------------------------------------- */
/* Board-wide firmware constants                                              */
/* -------------------------------------------------------------------------- */

#define CHARLIE_PIN_COUNT        5U
#define LED_COUNT                20U
#define BUTTON_DEBOUNCE_MS       30UL
#define BUTTON_HOLD_TIME_MS      6000UL /* Hold button this long to re-attune */

/* -------------------------------------------------------------------------- */
/* EEPROM layout                                                              */
/* -------------------------------------------------------------------------- */

#define EEPROM_ADDR_ATTUNEMENT   1U /* EEPROM byte 0 is intentionally unused. */
#define EEPROM_ADDR_FLAG         3U  /* Some padding for readability in dump. */
#define ATTUNEMENT_FLAG          0xA5U  /* EEPROM marker for valid attunement */

/* -------------------------------------------------------------------------- */
/* Roll behavior                                                              */
/* -------------------------------------------------------------------------- */

#define NAT1_BIAS_TRIGGER        3U     /* Start cursed bias after 3 nat1s    */
#define NAT20_BIAS_TRIGGER       3U     /* Start blessed bias after 3 nat20s  */

#define LOW_BIAS_MIN_ROLL        0U
#define LOW_BIAS_MAX_ROLL        5U

#define HIGH_BIAS_MIN_ROLL       15U
#define HIGH_BIAS_MAX_ROLL       19U

#define UPSET_NAT1_TRIGGER       11U    /* The dice is no longer joking      */

#define UPSET_INPUT_DENOMINATOR  8U
#define UPSET_INPUT_THRESHOLD    2U     /* 25% chance to ignore roll input   */

#define UPSET_GLITCH_DENOMINATOR 6U
#define UPSET_GLITCH_THRESHOLD   2U     /* ~33% chance to stutter before roll */

#define GODMODE_MIN_ROLL         15U
#define GODMODE_MAX_ROLL         19U

/* -------------------------------------------------------------------------- */
/* Attunement range                                                           */
/* -------------------------------------------------------------------------- */

#define ATTUNEMENT_MIN_VALUE     11U    /* Themed attunement range: 11..111   */
#define ATTUNEMENT_MAX_VALUE     111U

/* -------------------------------------------------------------------------- */
/* Character selection                                                        */
/* -------------------------------------------------------------------------- */

#define CHARACTER_ASHTAN         1U
#define CHARACTER_BARTHOLOMEW    2U
#define CHARACTER_FAWN           3U
#define CHARACTER_SALEM          4U
#define CHARACTER_VII            5U

#ifndef CHARACTER_ID
#define CHARACTER_ID             CHARACTER_VII
#endif

#if CHARACTER_ID == CHARACTER_ASHTAN
#define CHARACTER_NAME           "ASHTAN"
#elif CHARACTER_ID == CHARACTER_BARTHOLOMEW
#define CHARACTER_NAME           "BARTHOLOMEW"
#elif CHARACTER_ID == CHARACTER_FAWN
#define CHARACTER_NAME           "FAWN"
#elif CHARACTER_ID == CHARACTER_SALEM
#define CHARACTER_NAME           "SALEM"
#elif CHARACTER_ID == CHARACTER_VII
#define CHARACTER_NAME           "VII"
#else
#error "Invalid CHARACTER_ID"
#endif

#endif /* CONFIG_H */

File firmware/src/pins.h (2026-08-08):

/*
 * SPDX-License-Identifier: GPL-3.0-only
 *
 * Copyright (C) 2025 miss.molerat <bitshiftcrazy@posteo.de>
 */

#ifndef PINS_H
#define PINS_H

#include <avr/io.h>

/*
 * ATtiny84 pin mapping for the d20 PCB
 *
 *                    ATtiny84
 *               +-----------------+
 *         VCC --| 1            14 |-- GND
 *   NC / PB0  --| 2            13 |-- PA0 / A
 * BUTTON / PB1 -| 3            12 |-- PA1 / B
 * RESET / PB3 --| 4            11 |-- PA2 / C
 *      E / PB2 -| 5            10 |-- PA3 / D
 *   PAD / PA7 --| 6             9 |-- PA4 / SCK
 *   MOSI / PA6 -| 7             8 |-- PA5 / MISO
 *               +-----------------+
 *
 * Charlieplex lines:
 *   A -> PA0
 *   B -> PA1
 *   C -> PA2
 *   D -> PA3
 *   E -> PB2
 *
 * Other signals:
 *   BUTTON -> PB1
 *   TOUCH  -> PA7 (ADC7)
 */

/* ------------------------------------------------------------------------- */
/* Charlieplex LED driver pins                                               */
/* ------------------------------------------------------------------------- */

#define LED_A_PORT    PORTA
#define LED_A_DDR     DDRA
#define LED_A_PIN     PA0

#define LED_B_PORT    PORTA
#define LED_B_DDR     DDRA
#define LED_B_PIN     PA1

#define LED_C_PORT    PORTA
#define LED_C_DDR     DDRA
#define LED_C_PIN     PA2

#define LED_D_PORT    PORTA
#define LED_D_DDR     DDRA
#define LED_D_PIN     PA3

#define LED_E_PORT    PORTB
#define LED_E_DDR     DDRB
#define LED_E_PIN     PB2

/* ------------------------------------------------------------------------- */
/* Button input                                                              */
/* ------------------------------------------------------------------------- */

#define BUTTON_PORT   PORTB
#define BUTTON_DDR    DDRB
#define BUTTON_PINREG PINB
#define BUTTON_BIT    PB1

/* ------------------------------------------------------------------------- */
/* Capacitive touch pad                                                      */
/* ------------------------------------------------------------------------- */

#define TOUCH_PORT    PORTA
#define TOUCH_DDR     DDRA
#define TOUCH_PINREG  PINA
#define TOUCH_BIT     PA7

/* ADC channel for touch pad */
#define TOUCH_ADC_CHANNEL 7

#endif /* PINS_H */

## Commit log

2026-03-09 Initial open hardware release of the d20 PCB design
    [d20_pcb-B_Cu.gbr, d20_pcb-B_Mask.gbr, d20_pcb-B_Silkscreen.gbr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]
2026-05-06 HW: Add d20v3
    Changes:
    - move touchpad to analog pin
    - resize map artwork
    [d20_pcb-B_Cu.gbl, d20_pcb-B_Cu.gbr, d20_pcb-B_Mask.gbs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]
2026-08-08 FW: document fuses and expose fuse settings
2026-08-08 HW: add pink PCB pics to README
2026-08-08 HW: Include assembly instructions
